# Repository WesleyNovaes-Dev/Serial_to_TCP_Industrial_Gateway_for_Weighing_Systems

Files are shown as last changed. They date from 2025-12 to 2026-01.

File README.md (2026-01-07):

# Serial-to-TCP Industrial Gateway for Weighing Systems
# 🚀 Gateway IoT Industrial – Integração de Balanças RS-232 com Redes TCP/IP  
### **Projeto Empresarial – Indústria 4.0 (NCH Brasil)**  
**Desenvolvido por:** *Wesley Davi Zanon Novaes*  






---

## 🌐 Visão Geral

Este repositório apresenta um **Gateway IoT Industrial** projetado para **modernizar balanças legadas** (RS-232 e USB) e conectá-las diretamente a redes corporativas para uso em sistemas ERP, MES, supervisórios e aplicações de automação industrial.

Diferente de um TCC acadêmico, este projeto é **uma evolução real** implantada e utilizada na **NCH Brasil**, rodando diariamente em ambiente de produção — com integração já validada com o ERP atual da empresa.

O objetivo central é simples e poderoso:

### **Transformar qualquer balança serial em um dispositivo inteligente totalmente integrado à Indústria 4.0.**

Sem alterar o hardware da balança.  
Sem custos abusivos de modernização.  
Sem soluções proprietárias fechadas.

---

## 🎯 Principais Benefícios

✔ **Elimina apontamentos manuais** de pesagem  
✔ **Reduz erros operacionais**  
✔ **Transmite dados em tempo real** via TCP/IP  
✔ **Suporte a Wi-Fi corporativo, incluindo WPA2-Enterprise (802.1X)**  
✔ **Interface Web moderna** para configuração completa do dispositivo  
✔ **Compatível com ERPs, bancos de dados, supervisórios e APIs**  
✔ **Plug-and-Play** (conecta → configura → integra)

---

## 🧩 Arquitetura Geral

A solução é composta por dois pilares principais:

### **1) Gateway IoT (ESP32)**
Responsável por:
- Receber dados via **RS-232 (UART + MAX3232)** ou USB
- Limpar, validar e tratar frames recebidos
- Detectar mudanças de peso (filtro inteligente)
- Transmitir dados via:
  - **TCP (porta configurável)**
  - **Servidor de Log**
- Servir uma **interface web avançada responsiva**
- Oferecer:
  - Configuração Wi-Fi
  - Configuração Ethernet (quando disponível)
  - IP estático/DHCP
  - Hostname
  - Baud Rate
  - Formato JSON / Texto puro
  - Múltiplos clientes simultâneos

### **2) Backend Integrado (Node.js)**
- Recebe e processa dados enviados pelo gateway
- Permite integração com:
  - ERPs
  - Sistemas legados
  - Bancos de dados
  - Dashboards e BI
- Registro de eventos e logs

---

## 🛠️ Hardware Utilizado

| Componente | Função |
|---|---|
| **ESP32 DevKitC V4** | Core de processamento e Wi-Fi |
| **MAX3232** | Conversão RS-232 → TTL |
| **DB9** | Interface com balanças industriais |
| **Fonte 5V** | Alimentação |
| **Protótipo final** | Pronto para migração a PCB industrial |

---

## 🔌 Conexões (Pinout Completo – ESP32 + MAX3232 + W5500)

| **ESP32** | **Dispositivo** | **Pino no Dispositivo** | **Função** |
|---|---|---|---|
| **GPIO 16 (RX2)** | MAX3232 | TX | Recepção da Balança (RS-232 → TTL) |
| **GPIO 17 (TX2)** | MAX3232 | RX | Envio para Balança (TTL → RS-232) |
| **GND** | MAX3232 | GND | Referência elétrica |
| **3.3V** | MAX3232 | VCC | Alimentação do conversor |
| **GPIO 18 (SCK)** | W5500 | SCLK | Clock SPI |
| **GPIO 19 (MISO)**  | W5500 | MISO | Dados do W5500 → ESP32 |
| **GPIO 23 (MOSI)**  | W5500 | MOSI | Dados do ESP32 → W5500 |
| **GPIO 5 (CS)** | W5500 | CS | Chip Select do módulo Ethernet |
| **GPIO 4 (RST)** | W5500 | RST | Reset do módulo Ethernet |
| **GND** | W5500 | GND | Referência elétrica |
| **3.3V ou 5V*** | W5500 | VCC | Alimentação (depende do módulo)** |
| **GPIO 2** | LED Indicador | LED | LED de status do sistema |

> **\*** A maioria dos módulos W5500 funciona com alimentação 3.3V lógica, porém muitos incluem regulador interno e aceitam 5V — verificar o modelo utilizado.

---

## 🧠 Funcionamento do Firmware

1. **Inicialização**  
   - Carrega credenciais
   - Tenta reconectar à última rede
   - Caso falhe → inicia **Modo AP de Configuração**

2. **Leitura da Balança (RS-232)**  
   - Captura bytes brutos
   - Limpa caracteres inválidos
   - Normaliza a string de peso
   - Filtra repetições para reduzir tráfego

3. **Transmissão dos Dados**  
   - Via Socket TCP (porta configurável)
   - Suporte a múltiplos clientes
   - Mecanismos:
     - Retry
     - Reconexão automática
     - Heartbeat de latência

4. **Webserver Interno**  
   - Configuração completa da rede
   - Exibição de status em tempo real
   - Dashboard de balance connection
   - Opções avançadas:
     - IP estático
     - WINS
     - DNS configurável
     - SoftAP customizável

---

## 📡 Integração com ERP (CONFIRMADA)

Este projeto já está homologado com o **ERP utilizado pela NCH Brasil**.

Isso inclui:
- Recebimento automático das pesagens
- Inserção de dados em rotinas internas
- Substituição de processos manuais
- Automação completa do fluxo de entrada de dados

---

## 📸 Screenshots (Inserir após subir as imagens)

> **Coloque as imagens no repositório e substitua pelos links:**

---

## 🌐 Demonstração Online

Acesse a página oficial do projeto:  
👉 **[https://digitalintegration.site/](https://serial-to-tcp-industrial-gateway-we-three.vercel.app/)** 

---

## 📦 Como Instalar

### **1) Firmware ESP32**
- Abra o projeto na Arduino IDE / PlatformIO
- Compile e carregue
- Ligue o dispositivo

### **2) Configuração Inicial**
- Conecte ao Wi-Fi exposto pelo dispositivo (SoftAP)
- Acesse `192.168.4.1`
- Configure:
  - SSID
  - Senha
  - DHCP/IP Estático
  - Enterprise (se necessário)
- Salve e reinicie

### **3) Conexão com ERP / Servidor**
- Configure seu sistema para conectar ao socket TCP
- Utilize a porta definida no painel do dispositivo
- Pronto — a balança está integrada!

---

## 📊 Performance e Resultados

| Métrica | Resultado |
|---|---|
| Latência média | **< 50ms** |
| Perda de pacotes | **0%** |
| Uptime testado | **> 3 horas contínuas** |
| Economia de tráfego (filtro inteligente) | **~90%** |

---

## 💡 Casos de Uso

- Pesagem industrial em tempo real  
- Controle de estoque e logística  
- Linhas de produção  
- Inspeção e controle de qualidade  
- Integração com ERPs corporativos  
- Automação de processos

---

## 🏭 Uso na NCH Brasil

O sistema está em **operação real** em ambiente industrial:  
- Implantado e rodando diariamente  
- Integrado com ERP oficial  
- Acompanhado por operadores e gestores  
- Atualizado continuamente como produto interno  
- Base para expansão a múltiplas unidades

---

👉 **Link do Site Explicativo:**  
[Serial_to_TCP_Industrial_Gateway_for_Weighing_Systems]()

👉 **Repositório do Site Explicativo:**  
[Serial_to_TCP_Industrial_Gateway_for_Weighing_Systems](https://github.com/WesleyNovaes-Dev/Serial_to_TCP_Industrial_Gateway_Web)

## 🤝 Contribuições

Sugestões, melhorias e pull requests são bem-vindos!

---

## 👨‍💻 Autor

**Wesley Davi Zanon Novaes**  
Engenharia de Computação – Desenvolvimento Embarcado  
Sorocaba – SP, Brasil  
Formado: Dez/2025.

📧 E-mail: **wesleyzanon.dev@gmail.com**  
📱 WhatsApp: **(11) 96583-5656**  
🌐 LinkedIn: *[https://www.linkedin.com/in/wesley-novaes-641577193/]*  

---

## ⭐ Se este projeto te ajudou...

Deixe uma **estrela ⭐ no repositório**. Isso ajuda muito!

---

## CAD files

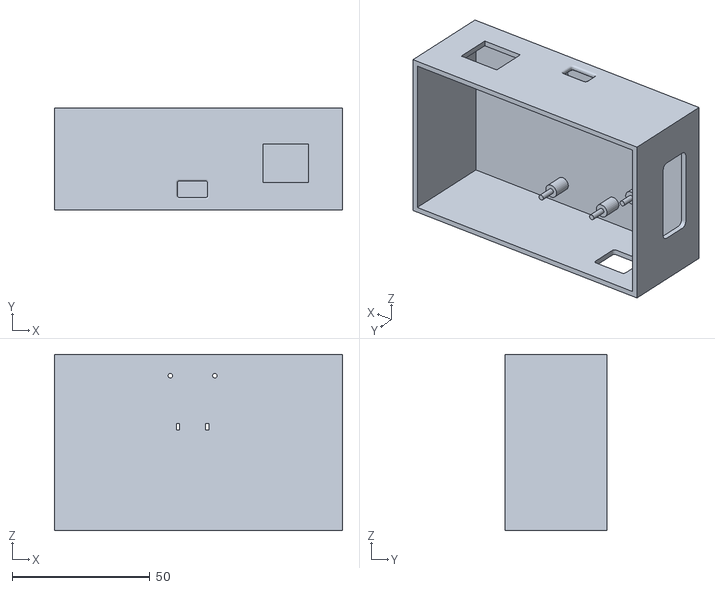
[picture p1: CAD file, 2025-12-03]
Case_3D/Corpo.stl
104.5 x 37.0 x 64.0

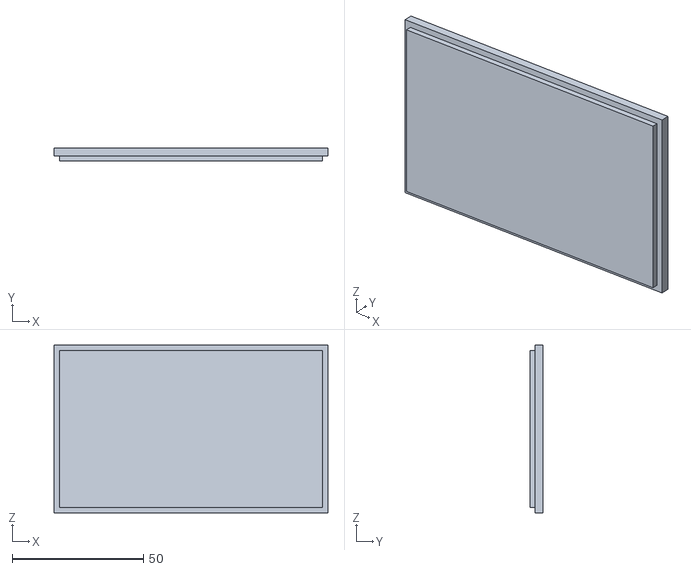
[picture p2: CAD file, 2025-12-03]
Case_3D/Tampa.stl
104.5 x 5.00 x 64.0

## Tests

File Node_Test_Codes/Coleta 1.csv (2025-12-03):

Data | Hora | DadoBruto | IP_Conexao
02/10/2025 | 18:27:20 | I00.010 | 10.128.32.178
02/10/2025 | 18:27:20 | I00.010 I00.010 I00.010 I00.010 I00.010 I00.010 I00.010 I00.010 I00.010 I00.010 I00.010 I00.010 I00.010 I00.010 I00.010 I00.010 I00.010 I00.010 I00.010 | 10.128.32.178
02/10/2025 | 18:27:21 | I00.030 I00.030 I00.030 I00.030 I00.030 I00.030 I00.030 I00.030 I00.030 I00.030 I00.030 I00.030 I00.030 I00.030 I00.030 I00.030 I00.030 I00.030 | 10.128.32.178
02/10/2025 | 18:27:21 | I00.030 I00.030 | 10.128.32.178
02/10/2025 | 18:27:21 | I00.050 I00.050 I00.050 I00.050 I00.050 I00.050 I00.050 I00.050 I00.050 I00.050 I00.050 I00.050 I00.050 I00.050 I00.050 I00.050 I00.050 I00.050 I00.050 I00.050 | 10.128.32.178
02/10/2025 | 18:27:21 | I00.065 I00.065 I00.065 I00.065 I00.065 I00.065 I00.065 I00.065 I00.065 I00.065 I00.065 I00.065 I00.065 I00.065 I00.065 I00.065 I00.065 I00.065 I00.065 I00.065 | 10.128.32.178
02/10/2025 | 18:27:21 | I00.070 I00.070 I00.070 I00.070 I00.070 I00.070 I00.070 I00.070 I00.070 I00.070 I00.070 I00.070 I00.070 I00.070 I00.070 I00.070 I00.070 I00.070 I00.070 I00.070 | 10.128.32.178
02/10/2025 | 18:27:22 | E00.070 | 10.128.32.178
02/10/2025 | 18:27:22 | E00.070 E00.070 E00.070 E00.070 E00.070 E00.070 E00.070 E00.070 E00.070 E00.070 E00.070 E00.070 E00.070 E00.070 E00.070 E00.070 E00.070 E00.070 E00.070 | 10.128.32.178
02/10/2025 | 18:27:23 | I00.075 | 10.128.32.178
02/10/2025 | 18:27:23 | I00.075 I00.075 I00.075 I00.075 I00.075 I00.075 I00.075 I00.075 I00.075 I00.075 I00.075 I00.075 I00.075 I00.075 I00.075 I00.075 I00.075 I00.075 I00.075 | 10.128.32.178
02/10/2025 | 18:27:23 | I00.090 | 10.128.32.178
02/10/2025 | 18:27:23 | I00.090 I00.090 I00.090 I00.090 I00.090 I00.090 I00.090 I00.090 I00.090 I00.090 I00.090 I00.090 I00.090 I00.090 I00.090 I00.090 I00.090 I00.090 I00.090 | 10.128.32.178
02/10/2025 | 18:27:23 | I00.110 | 10.128.32.178
02/10/2025 | 18:27:23 | I00.110 I00.110 I00.110 I00.110 I00.110 I00.110 I00.110 I00.110 I00.110 I00.110 I00.110 I00.110 I00.110 I00.110 I00.110 I00.110 I00.110 I00.110 I00.110 | 10.128.32.178
02/10/2025 | 18:27:23 | I00.130 I00.130 I00.130 I00.130 I00.130 I00.130 I00.130 I00.130 I00.130 I00.130 I00.130 I00.130 I00.130 I00.130 I00.130 I00.130 I00.130 I00.130 I00.130 I00.130 | 10.128.32.178
02/10/2025 | 18:27:23 | I00.125 | 10.128.32.178
02/10/2025 | 18:27:23 | I00.125 I00.125 I00.125 I00.125 I00.125 I00.125 I00.125 I00.125 I00.125 I00.125 I00.125 I00.125 I00.125 I00.125 I00.125 I00.125 I00.125 I00.125 I00.125 | 10.128.32.178
02/10/2025 | 18:27:24 | I00.130 | 10.128.32.178
02/10/2025 | 18:27:24 | I00.130 I00.130 I00.130 I00.130 I00.130 I00.130 I00.130 I00.130 I00.130 I00.130 I00.130 I00.130 I00.130 I00.130 I00.130 I00.130 I00.130 I00.130 I00.130 | 10.128.32.178
02/10/2025 | 18:27:24 | I00.140 | 10.128.32.178
02/10/2025 | 18:27:24 | I00.140 I00.140 I00.140 I00.140 I00.140 I00.140 I00.140 I00.140 I00.140 I00.140 I00.140 I00.140 I00.140 I00.140 I00.140 I00.140 I00.140 I00.140 I00.140 I00.160 I00.160 I00.160 I00.160 I00.160 I00.160 I00.160 | 10.128.32.178
02/10/2025 | 18:27:24 | I00.160 I00.160 I00.160 I00.160 I00.160 I00.160 I00.160 I00.160 I00.160 I00.160 I00.160 I00.160 I00.160 | 10.128.32.178
02/10/2025 | 18:27:24 | I00.175 I00.175 I00.175 I00.175 I00.175 I00.175 I00.175 I00.175 I00.175 I00.175 I00.175 I00.175 I00.175 I00.175 I00.175 I00.175 I00.175 I00.175 I00.175 | 10.128.32.178
02/10/2025 | 18:27:24 | I00.175 | 10.128.32.178
02/10/2025 | 18:27:24 | I00.180 I00.180 | 10.128.32.178
02/10/2025 | 18:27:24 | I00.180 I00.180 I00.180 I00.180 I00.180 I00.180 I00.180 I00.180 I00.180 I00.180 I00.180 I00.180 I00.180 I00.180 I00.180 I00.180 I00.180 I00.180 | 10.128.32.178
02/10/2025 | 18:27:25 | E00.180 | 10.128.32.178
02/10/2025 | 18:27:25 | E00.180 E00.180 E00.180 E00.180 E00.180 E00.180 E00.180 E00.180 E00.180 E00.180 E00.180 E00.180 E00.180 E00.180 E00.180 E00.180 E00.180 E00.180 E00.180 | 10.128.32.178
02/10/2025 | 18:27:29 | I00.175 | 10.128.32.178
02/10/2025 | 18:27:29 | I00.175 I00.175 I00.175 I00.175 I00.175 I00.175 I00.175 I00.175 I00.175 I00.175 I00.175 I00.175 I00.175 I00.175 I00.175 I00.175 I00.175 I00.175 I00.175 | 10.128.32.178
02/10/2025 | 18:27:29 | I00.150 | 10.128.32.178
02/10/2025 | 18:27:29 | I00.150 I00.150 I00.150 I00.150 I00.150 I00.150 I00.150 I00.150 I00.150 I00.150 I00.150 I00.150 I00.150 I00.150 I00.150 I00.150 I00.150 I00.150 I00.150 | 10.128.32.178
02/10/2025 | 18:27:30 | I00.110 | 10.128.32.178
02/10/2025 | 18:27:30 | I00.110 I00.110 I00.110 I00.110 I00.110 I00.110 I00.110 I00.110 I00.110 I00.110 I00.110 I00.110 I00.110 I00.110 I00.110 I00.110 I00.110 I00.110 I00.110 | 10.128.32.178
02/10/2025 | 18:27:30 | I00.075 I00.075 I00.075 I00.075 I00.075 I00.075 I00.075 I00.075 I00.075 I00.075 I00.075 I00.075 I00.075 I00.075 I00.075 I00.075 I00.075 I00.075 I00.075 I00.075 | 10.128.32.178
02/10/2025 | 18:27:30 | I00.055 I00.055 I00.055 I00.055 I00.055 I00.055 I00.055 I00.055 | 10.128.32.178
02/10/2025 | 18:27:30 | I00.055 I00.055 I00.055 I00.055 I00.055 I00.055 I00.055 I00.055 I00.055 I00.055 I00.055 I00.055 | 10.128.32.178
02/10/2025 | 18:27:30 | I00.050 | 10.128.32.178
02/10/2025 | 18:27:30 | I00.050 I00.050 I00.050 I00.050 I00.050 I00.050 I00.050 I00.050 I00.050 I00.050 I00.050 I00.050 I00.050 I00.050 I00.050 I00.050 I00.050 I00.050 I00.050 | 10.128.32.178
02/10/2025 | 18:27:31 | E00.050 | 10.128.32.178
02/10/2025 | 18:27:31 | E00.050 E00.050 E00.050 E00.050 E00.050 E00.050 E00.050 E00.050 E00.050 E00.050 E00.050 E00.050 E00.050 E00.050 E00.050 E00.050 E00.050 E00.050 E00.050 | 10.128.32.178
02/10/2025 | 18:27:31 | I00.045 | 10.128.32.178
02/10/2025 | 18:27:31 | I00.045 I00.045 I00.045 I00.045 I00.045 I00.045 I00.045 I00.045 I00.045 I00.045 I00.045 I00.045 I00.045 I00.045 I00.045 I00.045 I00.045 I00.045 I00.045 | 10.128.32.178
02/10/2025 | 18:27:32 | I00.035 I00.035 I00.035 I00.035 I00.035 I00.035 I00.035 I00.035 I00.035 I00.035 I00.035 I00.035 I00.035 I00.035 I00.035 I00.035 | 10.128.32.178
02/10/2025 | 18:27:32 | I00.035 I00.035 I00.035 I00.035 | 10.128.32.178
02/10/2025 | 18:27:32 | I00.020 | 10.128.32.178
02/10/2025 | 18:27:32 | I00.020 I00.020 I00.020 I00.020 I00.020 I00.020 I00.020 I00.020 I00.020 I00.020 I00.020 I00.020 I00.020 I00.020 I00.020 I00.020 I00.020 I00.020 I00.020 | 10.128.32.178
02/10/2025 | 18:27:32 | I00.005 | 10.128.32.178
02/10/2025 | 18:27:32 | I00.005 I00.005 I00.005 I00.005 I00.005 I00.005 I00.005 I00.005 I00.005 I00.005 I00.005 I00.005 I00.005 I00.005 I00.005 I00.005 I00.005 I00.005 I00.005 I00.000 I00.000 I00.000 I00.000 I00.000 I00.000 I00.000 I00.000 I00.000 I00.000 I00.000 I00.000 I00.000 I00.000 I00.000 I00.000 I00.000 I00.000 I00.000 I00.000 | 10.128.32.178
02/10/2025 | 18:27:33 | E00.000 | 10.128.32.178
02/10/2025 | 18:27:33 | E00.000 E00.000 E00.000 E00.000 E00.000 E00.000 E00.000 E00.000 E00.000 E00.000 E00.000 E00.000 E00.000 E00.000 E00.000 E00.000 E00.000 E00.000 E00.000 | 10.128.32.178

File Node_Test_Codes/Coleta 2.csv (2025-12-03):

Data | Hora | DadoBruto | IP_Conexao
02/10/2025 | 18:29:15 | I00.015 | 10.128.32.178
02/10/2025 | 18:29:15 | I00.015 I00.015 I00.015 I00.015 I00.015 I00.015 I00.015 I00.015 I00.015 I00.015 I00.015 I00.015 I00.015 I00.015 I00.015 I00.015 I00.015 I00.015 I00.015 | 10.128.32.178
02/10/2025 | 18:29:16 | I00.000 | 10.128.32.178
02/10/2025 | 18:29:16 | I00.000 I00.000 I00.000 I00.000 I00.000 I00.000 I00.000 I00.000 I00.000 I00.000 I00.000 I00.000 I00.000 I00.000 I00.000 I00.000 I00.000 I00.000 I00.000 | 10.128.32.178
02/10/2025 | 18:29:17 | E00.000 | 10.128.32.178
02/10/2025 | 18:29:17 | E00.000 E00.000 E00.000 E00.000 E00.000 E00.000 E00.000 E00.000 E00.000 E00.000 E00.000 E00.000 E00.000 E00.000 E00.000 E00.000 E00.000 E00.000 E00.000 | 10.128.32.178
02/10/2025 | 18:29:20 | I00.015 | 10.128.32.178
02/10/2025 | 18:29:20 | I00.015 I00.015 I00.015 I00.015 I00.015 I00.015 I00.015 I00.015 I00.015 I00.015 I00.015 I00.015 I00.015 I00.015 I00.015 I00.015 I00.015 I00.015 I00.015 | 10.128.32.178
02/10/2025 | 18:29:20 | I00.040 | 10.128.32.178
02/10/2025 | 18:29:20 | I00.040 I00.040 I00.040 I00.040 I00.040 I00.040 I00.040 I00.040 I00.040 I00.040 I00.040 I00.040 I00.040 I00.040 I00.040 I00.040 I00.040 I00.040 I00.040 | 10.128.32.178
02/10/2025 | 18:29:20 | I00.060 I00.060 I00.060 I00.060 | 10.128.32.178
02/10/2025 | 18:29:20 | I00.060 I00.060 I00.060 I00.060 I00.060 I00.060 I00.060 I00.060 I00.060 I00.060 I00.060 I00.060 I00.060 I00.060 I00.060 I00.060 | 10.128.32.178
02/10/2025 | 18:29:20 | I00.070 | 10.128.32.178
02/10/2025 | 18:29:20 | I00.070 I00.070 I00.070 I00.070 I00.070 I00.070 I00.070 I00.070 I00.070 I00.070 I00.070 I00.070 I00.070 I00.070 I00.070 I00.070 I00.070 I00.070 I00.070 | 10.128.32.178
02/10/2025 | 18:29:21 | E00.070 | 10.128.32.178
02/10/2025 | 18:29:21 | E00.070 E00.070 E00.070 E00.070 E00.070 E00.070 E00.070 E00.070 E00.070 E00.070 E00.070 E00.070 E00.070 E00.070 E00.070 E00.070 E00.070 E00.070 E00.070 | 10.128.32.178
02/10/2025 | 18:29:24 | I00.080 | 10.128.32.178
02/10/2025 | 18:29:24 | I00.080 I00.080 I00.080 I00.080 I00.080 I00.080 I00.080 I00.080 I00.080 I00.080 I00.080 I00.080 I00.080 I00.080 I00.080 I00.080 I00.080 I00.080 I00.080 | 10.128.32.178
02/10/2025 | 18:29:24 | I00.100 I00.100 I00.100 I00.100 I00.100 I00.100 I00.100 I00.100 I00.100 I00.100 I00.100 I00.100 | 10.128.32.178
02/10/2025 | 18:29:24 | I00.100 I00.100 I00.100 I00.100 I00.100 I00.100 I00.100 I00.100 | 10.128.32.178
02/10/2025 | 18:29:24 | I00.115 | 10.128.32.178
02/10/2025 | 18:29:24 | I00.115 I00.115 I00.115 I00.115 I00.115 I00.115 I00.115 I00.115 I00.115 I00.115 I00.115 I00.115 I00.115 I00.115 I00.115 I00.115 I00.115 I00.115 I00.115 | 10.128.32.178
02/10/2025 | 18:29:24 | I00.125 I00.125 I00.125 I00.125 I00.125 I00.125 | 10.128.32.178
02/10/2025 | 18:29:25 | I00.125 I00.125 I00.125 I00.125 I00.125 I00.125 I00.125 I00.125 I00.125 I00.125 I00.125 I00.125 I00.125 I00.125 | 10.128.32.178
02/10/2025 | 18:29:26 | E00.125 | 10.128.32.178
02/10/2025 | 18:29:26 | E00.125 E00.125 E00.125 E00.125 E00.125 E00.125 E00.125 E00.125 E00.125 E00.125 E00.125 E00.125 E00.125 E00.125 E00.125 E00.125 E00.125 E00.125 E00.125 | 10.128.32.178
02/10/2025 | 18:29:27 | I00.120 | 10.128.32.178
02/10/2025 | 18:29:27 | I00.120 I00.120 I00.120 I00.120 I00.120 I00.120 I00.120 I00.120 I00.120 I00.120 I00.120 I00.120 I00.120 I00.120 I00.120 I00.120 I00.120 I00.120 I00.120 | 10.128.32.178
02/10/2025 | 18:29:27 | I00.095 I00.095 I00.095 I00.095 I00.095 I00.095 I00.095 I00.095 I00.095 I00.095 I00.095 I00.095 I00.095 I00.095 I00.095 I00.095 I00.095 I00.095 I00.095 I00.095 | 10.128.32.178
02/10/2025 | 18:29:27 | I00.055 | 10.128.32.178
02/10/2025 | 18:29:27 | I00.055 I00.055 I00.055 I00.055 I00.055 I00.055 I00.055 I00.055 I00.055 I00.055 I00.055 I00.055 I00.055 I00.055 I00.055 I00.055 I00.055 I00.055 I00.055 | 10.128.32.178
02/10/2025 | 18:29:28 | I00.020 I00.020 I00.020 I00.020 I00.020 I00.020 I00.020 I00.020 I00.020 I00.020 I00.020 I00.020 I00.020 I00.020 I00.020 I00.020 I00.020 I00.020 I00.020 I00.020 | 10.128.32.178
02/10/2025 | 18:29:28 | I00.005 I00.005 I00.005 I00.005 I00.005 I00.005 | 10.128.32.178
02/10/2025 | 18:29:28 | I00.005 I00.005 I00.005 I00.005 I00.005 I00.005 I00.005 I00.005 I00.005 I00.005 I00.005 I00.005 I00.005 I00.005 | 10.128.32.178
02/10/2025 | 18:29:28 | I00.000 I00.000 I00.000 I00.000 I00.000 I00.000 I00.000 I00.000 I00.000 I00.000 I00.000 I00.000 I00.000 I00.000 I00.000 I00.000 I00.000 I00.000 I00.000 I00.000 | 10.128.32.178
02/10/2025 | 18:29:29 | E00.000 | 10.128.32.178
02/10/2025 | 18:29:29 | E00.000 E00.000 E00.000 E00.000 E00.000 E00.000 E00.000 E00.000 E00.000 E00.000 E00.000 E00.000 E00.000 E00.000 E00.000 E00.000 E00.000 E00.000 E00.000 | 10.128.32.178

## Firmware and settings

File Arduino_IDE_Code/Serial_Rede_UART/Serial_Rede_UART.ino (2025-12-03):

#include <WiFi.h>
#include <ESPmDNS.h>
#include <WiFiUdp.h>
#include <ArduinoOTA.h>
#include <Preferences.h>
#include "esp_eap_client.h"
#include <IPAddress.h>
#include <vector>
#include <stdarg.h>
#include <memory>

#include <SPI.h>
#include <Ethernet.h>

// ========== 1. DEFINIÇÕES E PINAGEM ==========
const int ledPin = 2;

// SERIAL RS232 (Balança)
#define RS232_TX 17
#define RS232_RX 16

// W5500 SPI pins
#define W5500_SCLK  18
#define W5500_MISO  19
#define W5500_MOSI  23
#define W5500_CS    5
#define W5500_RST   4

// MAC Address para Ethernet
byte mac[] = { 0xDE, 0xAD, 0xBE, 0xEF, 0xFE, 0x05 };

// Configurações de Tempo
const long SOFTAP_GRACE_PERIOD_MS = 60000;
const long NETWORK_CHECK_INTERVAL = 15000; // 15 segundos para reconexão
const unsigned long WEB_POST_READ_TIMEOUT = 800;
const unsigned long RS232_POLL_INTERVAL = 1;
const unsigned long STATUS_LOG_INTERVAL = 60000; // 1 minuto
const unsigned long BALANCE_CHECK_INTERVAL = 5000; // Verificar balança a cada 5s

// ========== 2. ESTRUTURAS E ENUMS ==========
struct AuthClient {
    std::shared_ptr<Client> client;
    String ip;
    unsigned long lastSentMs = 0;
};

struct WinsConfig {
    String wins1;
    String wins2;
};

enum NetworkMode { 
    NET_NONE, 
    NET_SOFTAP, 
    NET_WIFI, 
    NET_ETHERNET 
};

enum LedStatus {
    LED_OFF,
    LED_ON,
    LED_BLINK_SLOW,    // Modo AP/Configuração
    LED_BLINK_FAST,    // Conectando
    LED_BLINK_DOUBLE   // Erro
};

// ========== 3. OBJETOS GLOBAIS ==========
NetworkMode currentMode = NET_NONE;
LedStatus currentLedStatus = LED_OFF;

HardwareSerial SerialRS232(2);
Preferences prefs;

// Servidores
WiFiServer wifiWeb(80);
WiFiServer wifiData(9000);
WiFiServer wifiLog(5000);

EthernetServer ethWeb(80);
EthernetServer ethData(9000);
EthernetServer ethLog(5000);

// Clientes
std::vector<AuthClient> dataClients;
std::vector<AuthClient> logClients;

// ========== 4. CONFIGURAÇÕES PERSISTENTES ==========
String adminPassword = "";
String deviceHostname = "esp32-balanca-Generic";
long rs232Baud = 9600;
uint16_t dataPort = 9000;
uint16_t logPort = 5000;
String lastSoftApPass = "12345678";
String softApSSID = "ESP32_Balanca_Config_Generic";

// Configurações de Rede
String lastSSID = "", lastPass = "", lastUser = "";
bool lastEnterprise = false;
bool lastUseStaticIP = false;
String lastStaticIP = "", lastSubnet = "", lastGateway = "", lastDns1 = "", lastDns2 = "";
WinsConfig winsConfig = {"", ""};

// Configurações do Sistema
bool lastUseLCD = false;
bool enableLineChangeDetector = false;
int dataSendFormat = 1;
bool sendAlways = true;

// ========== 5. VARIÁVEIS DE ESTADO ==========
bool connectionJustSucceeded = false;
unsigned long connectionSuccessTime = 0;
unsigned long ledPreviousMillis = 0;
const long ledInterval = 500;
bool isRs232Active = false;
unsigned long lastNetworkCheck = 0;
unsigned long softApStartTime = 0;
unsigned long lastStatusLogTime = 0;
unsigned long lastBalanceCheck = 0;
unsigned long lastReconnectAttempt = 0;

// Buffer de Dados
String currentWeightBuffer = "";
String lastSentWeight = "";
String serialUsbBuffer = "";

// Controle LED
unsigned long lastLedChange = 0;
int ledBlinkState = LOW;

// Estado do Sistema
bool balanceConnected = false;
bool networkConnected = false;
String lastWebAlert = "";

// ========== 6. PROTÓTIPOS ==========
void app_log(const char *format, ...);
void saveCredentials();
void loadCredentials();
void clearCredentials();
void startSoftAP();
void stopSoftAP();
void stopNetwork();
bool startEthernet();
bool startWiFi();
void manageNetwork();
void handleDataClient();
void handleLogClients();
void broadcastWeightAndClientStatusToLog(String cleanWeight);
String urlDecode(String str);
String getParam(String req, String key);
template <typename T> void handleWebClientGeneric(T client);

// Novas funções
void setLedStatus(LedStatus status);
void updateLed();
void performFactoryReset();
void processSerialUSBCommands();
void resetW5500();
IPAddress strToIP(String s);
void checkSerialState();
String cleanWeightLine(const String &line);
void broadcastDataToClients(const String &payload);
void processRS232();
void startServicesHibrido();
void checkBalanceConnection();
void attemptReconnect();
String getNetworkStatusJSON();
String scanWiFiNetworks();
String generateWebInterface();

// ========== 7. SISTEMA DE LOG COMPLETO ==========
void app_log(const char *format, ...) {
    char buf[512];
    va_list args;
    va_start(args, format);
    vsnprintf(buf, sizeof(buf), format, args);
    va_end(args);
    
    // Log na Serial
    Serial.print(buf);
    
    // Log para clientes de LOG apenas se houver conexão de rede
    if (networkConnected && dataClients.empty()) {
        for (int i = (int)logClients.size() - 1; i >= 0; i--) {
            if (logClients[i].client && logClients[i].client->connected()) {
                logClients[i].client->write((uint8_t*)buf, strlen(buf));
            } else {
                if (logClients[i].client) logClients[i].client->stop();
                logClients.erase(logClients.begin() + i);
            }
        }
    }
}

// ========== 8. SISTEMA LED ==========
void setLedStatus(LedStatus status) {
    currentLedStatus = status;
    lastLedChange = millis();
    ledBlinkState = LOW;
    
    switch(status) {
        case LED_OFF:
            digitalWrite(ledPin, LOW);
            break;
        case LED_ON:
            digitalWrite(ledPin, HIGH);
            break;
        case LED_BLINK_SLOW:  // 1Hz - Modo AP
        case LED_BLINK_FAST:  // 2Hz - Conectando
        case LED_BLINK_DOUBLE: // Pisca duplo - Erro
            digitalWrite(ledPin, LOW);
            break;
    }
}

void updateLed() {
    unsigned long currentMillis = millis();
    long interval = 0;
    
    switch(currentLedStatus) {
        case LED_BLINK_SLOW:
            interval = 1000; break;
        case LED_BLINK_FAST:
            interval = 500; break;
        case LED_BLINK_DOUBLE:
            interval = 300; break;
        default:
            return;
    }
    
    if (currentMillis - lastLedChange >= interval) {
        lastLedChange = currentMillis;
        
        if (currentLedStatus == LED_BLINK_DOUBLE) {
            // Pisca duplo especial
            static int doubleBlinkPhase = 0;
            switch(doubleBlinkPhase) {
                case 0: digitalWrite(ledPin, HIGH); break;
                case 1: digitalWrite(ledPin, LOW); break;
                case 2: digitalWrite(ledPin, HIGH); break;
                case 3: digitalWrite(ledPin, LOW); break;
            }
            doubleBlinkPhase = (doubleBlinkPhase + 1) % 4;
        } else {
            // Pisca normal
            ledBlinkState = !ledBlinkState;
            digitalWrite(ledPin, ledBlinkState);
        }
    }
}

// ========== 9. BROADCAST E LOGS ==========
void broadcastWeightAndClientStatusToLog(String cleanWeight) {
    if (logClients.empty() || !networkConnected) return;
    
    String dataClientList = "";
    for (const auto& client : dataClients) {
        if (!dataClientList.isEmpty()) dataClientList += ", ";
        dataClientList += client.ip;
    }
    if (dataClientList.isEmpty()) dataClientList = "Nenhum";

    String logClientList = "";
    for (const auto& client : logClients) {
        if (!logClientList.isEmpty()) logClientList += ", ";
        logClientList += client.ip;
    }

    String balanceStatus = balanceConnected ? "Conectada" : "DESLIGADA";
    
    String logPayload = "[PESO]|" + cleanWeight +
                       "|Balança: " + balanceStatus +
                       "|Clientes Dados (" + String(dataClients.size()) + "): " + dataClientList +
                       "|Clientes Log (" + String(logClients.size()) + "): " + logClientList +
                       "|Rede: " + String(currentMode == NET_ETHERNET ? "CABO" : 
                                       currentMode == NET_WIFI ? "WiFi" : "AP") +
                       "\n";

    for (int i = (int)logClients.size() - 1; i >= 0; i--) {
        if (logClients[i].client && logClients[i].client->connected()) {
            logClients[i].client->write((const uint8_t*)logPayload.c_str(), logPayload.length());
        } else {
            if (logClients[i].client) logClients[i].client->stop();
            logClients.erase(logClients.begin() + i);
        }
    }
}

// ========== 10. GESTÃO DE REDE REFATORADA ==========
IPAddress strToIP(String s) { 
    IPAddress ip; 
    if (s.length() > 0) {
        ip.fromString(s); 
    }
    return ip; 
}

void resetW5500() {
    pinMode(W5500_RST, OUTPUT);
    digitalWrite(W5500_RST, LOW); 
    delay(200);
    digitalWrite(W5500_RST, HIGH); 
    delay(200);
}

void stopNetwork() {
    app_log("[REDE] Parando serviços de rede...\n");
    
    if (currentMode == NET_WIFI || currentMode == NET_SOFTAP) {
        WiFi.disconnect(true);
        WiFi.mode(WIFI_OFF);
    }
    
    currentMode = NET_NONE;
    networkConnected = false;
    
    // Limpa clientes
    for (auto &c : dataClients) if (c.client) c.client->stop();
    for (auto &c : logClients) if (c.client) c.client->stop();
    dataClients.clear(); 
    logClients.clear();
    
    setLedStatus(LED_BLINK_SLOW);
}

void startServicesHibrido() {
    app_log("[SERVICOS] Iniciando serviços...\n");
    
    if (currentMode == NET_ETHERNET) {
        ethWeb.begin();
        ethData.begin();
        ethLog.begin();
        app_log("[SERVICOS] Servidores Ethernet iniciados\n");
    } else {
        wifiWeb.begin();
        wifiData.begin(dataPort);
        wifiLog.begin(logPort);
        app_log("[SERVICOS] Servidores WiFi iniciados\n");
    }

    // mDNS
    MDNS.end();
    if (!MDNS.begin(deviceHostname.c_str())) {
        app_log("[SERVICOS] Erro ao iniciar mDNS!\n");
    } else {
        app_log("[SERVICOS] mDNS: http://%s.local\n", deviceHostname.c_str());
        MDNS.addService("http", "tcp", 80);
        MDNS.addService("balanca-data", "tcp", dataPort);
    }

    // OTA apenas para WiFi
    if (currentMode == NET_WIFI || currentMode == NET_SOFTAP) {
        ArduinoOTA.setHostname(deviceHostname.c_str());
        if (adminPassword.length() > 0) {
            ArduinoOTA.setPassword(adminPassword.c_str());
        }
        ArduinoOTA.begin();
        app_log("[SERVICOS] OTA pronto\n");
    }
    
    app_log("[SERVICOS] Serviços online - Web:80, Dados:%d, Log:%d\n", dataPort, logPort);
    connectionJustSucceeded = true;
    connectionSuccessTime = millis();
    networkConnected = true;
}

bool startEthernet() {
    stopNetwork();
    app_log("[ETHERNET] Iniciando conexão por cabo...\n");
    setLedStatus(LED_BLINK_FAST);
    
    resetW5500();
    Ethernet.init(W5500_CS);

    int dhcpStatus = 0;
    if (lastUseStaticIP && lastStaticIP.length() > 0) {
        app_log("[ETHERNET] IP Estático: %s\n", lastStaticIP.c_str());
        IPAddress ip = strToIP(lastStaticIP);
        IPAddress gateway = strToIP(lastGateway);
        IPAddress subnet = strToIP(lastSubnet);
        IPAddress dns1 = strToIP(lastDns1);
        IPAddress dns2 = strToIP(lastDns2);
        
        if (dns1 != INADDR_NONE) {
            Ethernet.begin(mac, ip, dns1, gateway, subnet);
        } else {
            Ethernet.begin(mac, ip, gateway, subnet);
        }
        dhcpStatus = 1;
    } else {
        app_log("[ETHERNET] DHCP: Solicitando...\n");
        dhcpStatus = Ethernet.begin(mac, 10000); // Timeout de 10s
    }

    if (dhcpStatus == 0) {
        app_log("[ETHERNET] Falha - Sem cabo/DHCP\n");
        setLedStatus(LED_BLINK_DOUBLE);
        return false;
    }

    app_log("[ETHERNET] Conectado! IP: %s\n", Ethernet.localIP().toString().c_str());
    currentMode = NET_ETHERNET;
    startServicesHibrido();
    setLedStatus(LED_ON);
    return true;
}

bool startWiFi() {
    stopNetwork();
    
    if (lastSSID == "") { 
        app_log("[WIFI] Nenhuma rede configurada\n"); 
        return false; 
    }

    app_log("[WIFI] Conectando: %s\n", lastSSID.c_str());
    setLedStatus(LED_BLINK_FAST);
    
    WiFi.mode(WIFI_STA);

    // Configuração IP estático para WiFi
    if (lastUseStaticIP && lastStaticIP.length() > 0) {
        app_log("[WIFI] IP Estático: %s\n", lastStaticIP.c_str());
        IPAddress ip = strToIP(lastStaticIP);
        IPAddress gateway = strToIP(lastGateway);
        IPAddress subnet = strToIP(lastSubnet);
        IPAddress dns1 = strToIP(lastDns1);
        IPAddress dns2 = strToIP(lastDns2);
        
        if (dns1 != INADDR_NONE || dns2 != INADDR_NONE) {
            if (dns1 != INADDR_NONE && dns2 != INADDR_NONE) {
                WiFi.config(ip, gateway, subnet, dns1, dns2);
            } else if (dns1 != INADDR_NONE) {
                WiFi.config(ip, gateway, subnet, dns1);
            }
        } else {
            WiFi.config(ip, gateway, subnet);
        }
    }

    // Configuração Enterprise 802.1x
    if (lastEnterprise) {
        app_log("[WIFI] Modo Enterprise 802.1x - Usuário: %s\n", lastUser.c_str());
        esp_eap_client_set_identity((uint8_t*)lastUser.c_str(), lastUser.length());
        esp_eap_client_set_username((uint8_t*)lastUser.c_str(), lastUser.length());
        esp_eap_client_set_password((uint8_t*)lastPass.c_str(), lastPass.length());
        esp_wifi_sta_enterprise_enable();
        WiFi.begin(lastSSID.c_str());
    } else {
        WiFi.begin(lastSSID.c_str(), lastPass.c_str());
    }

    int attempts = 0;
    while (WiFi.status() != WL_CONNECTED && attempts < 30) { // 15s timeout
        delay(500); 
        app_log("."); 
        attempts++;
        if (attempts % 4 == 0) yield();
    }
    app_log("\n");

    if (WiFi.status() == WL_CONNECTED) {
        app_log("[WIFI] Conectado! IP: %s\n", WiFi.localIP().toString().c_str());
        currentMode = NET_WIFI;
        startServicesHibrido();
        setLedStatus(LED_ON);
        return true;
    } else {
        app_log("[WIFI] Falha na conexão\n");
        setLedStatus(LED_BLINK_DOUBLE);
        return false;
    }
}

void startSoftAP() {
    stopNetwork();
    app_log("[SOFTAP] Iniciando modo configuração...\n");
    
    WiFi.mode(WIFI_AP_STA);
    WiFi.softAP(softApSSID.c_str(), lastSoftApPass.c_str());
    
    currentMode = NET_SOFTAP;
    startServicesHibrido();
    
    IPAddress IP = WiFi.softAPIP();
    app_log("[SOFTAP] Pronto! IP: %s - Senha: %s\n", IP.toString().c_str(), lastSoftApPass.c_str());
    
    softApStartTime = millis();
    setLedStatus(LED_BLINK_SLOW);
}

void stopSoftAP() {
    if (WiFi.getMode() == WIFI_AP_STA) {
        WiFi.softAPdisconnect(true);
        app_log("[SOFTAP] Desativado\n");
    }
}

void attemptReconnect() {
    if (millis() - lastReconnectAttempt < NETWORK_CHECK_INTERVAL) return;
    lastReconnectAttempt = millis();
    
    // Verifica se temos credenciais salvas
    if (lastSSID.length() > 0) {
        app_log("[RECONEXAO] Tentando reconectar à rede salva...\n");
        if (startWiFi()) {
            app_log("[RECONEXAO] Reconexão bem-sucedida!\n");
        } else {
            app_log("[RECONEXAO] Falha na reconexão\n");
        }
    }
}

void manageNetwork() {
    if (millis() - lastNetworkCheck < NETWORK_CHECK_INTERVAL) return;
    lastNetworkCheck = millis();

    // Verifica status do cabo Ethernet
    bool cableConnected = (Ethernet.linkStatus() == LinkON);
    bool wifiConnected = (WiFi.status() == WL_CONNECTED);

    // Lógica de failover inteligente
    if (cableConnected && currentMode != NET_ETHERNET) {
        app_log("[FAILOVER] Cabo detectado - Mudando para Ethernet\n");
        if (!startEthernet()) {
            if (currentMode == NET_NONE && !startWiFi()) {
                startSoftAP();
            }
        }
    } 
    else if (!cableConnected && currentMode == NET_ETHERNET) {
        app_log("[FAILOVER] Cabo desconectado - Tentando WiFi\n");
        if (!startWiFi()) {
            app_log("[FAILOVER] WiFi falhou - Iniciando SoftAP\n");
            startSoftAP();
        }
    }
    // Se desconectou do WiFi, tenta reconectar ou vai para Ethernet
    else if (currentMode == NET_WIFI && !wifiConnected) {
        app_log("[FAILOVER] WiFi desconectado - Tentando reconectar\n");
        attemptReconnect();
    }
    // Se está em modo AP mas há redes salvas, tenta reconectar periodicamente
    else if (currentMode == NET_SOFTAP && lastSSID.length() > 0) {
        attemptReconnect();
    }

    // Timeout do SoftAP se ninguém conectar
    if (currentMode == NET_SOFTAP && WiFi.softAPgetStationNum() == 0) {
        if (millis() - softApStartTime > (SOFTAP_GRACE_PERIOD_MS * 5)) {
            app_log("[SOFTAP] Timeout - Tentando reconexão...\n");
            if (lastSSID.length() > 0 && !startWiFi()) {
                if (cableConnected && !startEthernet()) {
                    app_log("[SOFTAP] Nenhuma conexão disponível - Mantendo AP\n");
                    softApStartTime = millis(); // Reseta o timer
                }
            }
        }
    }
}

// ========== 11. PERSISTÊNCIA ==========
void saveCredentials() {
    prefs.begin("wifiCreds", false);
    prefs.putString("ssid", lastSSID);
    prefs.putString("pass", lastPass);
    prefs.putString("user", lastUser);
    prefs.putBool("enterprise", lastEnterprise);
    prefs.putBool("useStatic", lastUseStaticIP);
    if (lastUseStaticIP) {
        prefs.putString("staticIP", lastStaticIP);
        prefs.putString("subnet", lastSubnet);
        prefs.putString("gateway", lastGateway);
        prefs.putString("dns1", lastDns1);
        prefs.putString("dns2", lastDns2);
        prefs.putString("wins1", winsConfig.wins1);
        prefs.putString("wins2", winsConfig.wins2);
    }
    prefs.end();

    prefs.begin("sysConfig", false);
    prefs.putString("admPass", adminPassword);
    prefs.putString("hostname", deviceHostname);
    prefs.putUShort("dPort", dataPort);
    prefs.putUShort("lPort", logPort);
    prefs.putLong("baud", rs232Baud);
    prefs.putInt("dsf", dataSendFormat);
    prefs.putString("softap", lastSoftApPass);
    prefs.putString("softapssid", softApSSID);
    prefs.putBool("useLCD", lastUseLCD);
    prefs.putBool("sendAlways", sendAlways);
    prefs.end();
    
    app_log("[CONFIG] Credenciais salvas\n");
}

void loadCredentials() {
    prefs.begin("wifiCreds", true);
    lastSSID = prefs.getString("ssid", "");
    lastPass = prefs.getString("pass", "");
    lastUser = prefs.getString("user", "");
    lastEnterprise = prefs.getBool("enterprise", false);
    lastUseStaticIP = prefs.getBool("useStatic", false);
    lastStaticIP = prefs.getString("staticIP", "");
    lastSubnet = prefs.getString("subnet", "");
    lastGateway = prefs.getString("gateway", "");
    lastDns1 = prefs.getString("dns1", "");
    lastDns2 = prefs.getString("dns2", "");
    winsConfig.wins1 = prefs.getString("wins1", "");
    winsConfig.wins2 = prefs.getString("wins2", "");
    prefs.end();

    prefs.begin("sysConfig", true);
    adminPassword = prefs.getString("admPass", "");
    deviceHostname = prefs.getString("hostname", "esp32-balanca-Generic");
    dataPort = prefs.getUShort("dPort", 9000);
    logPort = prefs.getUShort("lPort", 5000);
    rs232Baud = prefs.getLong("baud", 9600);
    dataSendFormat = prefs.getInt("dsf", 1);
    lastSoftApPass = prefs.getString("softap", "12345678");
    softApSSID = prefs.getString("softapssid", "ESP32_Balanca_Config_Generic");
    lastUseLCD = prefs.getBool("useLCD", true);
    sendAlways = prefs.getBool("sendAlways", true);
    prefs.end();

    enableLineChangeDetector = lastUseLCD;
    app_log("[CONFIG] Configurações carregadas\n");
}
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
void loop() {
    // Gestão de Rede
    manageNetwork();

    // Atualização LED
    updateLed();

    // OTA Updates (apenas WiFi)
    if (currentMode == NET_WIFI || currentMode == NET_SOFTAP || currentMode == NET_ETHERNET) {
        ArduinoOTA.handle();
    }

    // Desativa SoftAP após conexão estabelecida
    if (currentMode != NET_SOFTAP && connectionJustSucceeded && 
        (millis() - connectionSuccessTime > SOFTAP_GRACE_PERIOD_MS)) {
        stopSoftAP(); 
        connectionJustSucceeded = false;
    }

    // LOG DE STATUS A CADA 1 MINUTO (apenas se houver conexão de rede)
    if (networkConnected && millis() - lastStatusLogTime > STATUS_LOG_INTERVAL) {
        lastStatusLogTime = millis();
        String statusMsg = "\n[STATUS 1min] -----------------------------\n";
        statusMsg += "Conexao: " + String(currentMode == NET_ETHERNET ? "CABO (RJ45)" : (currentMode == NET_WIFI ? "WIFI" : "AP Mode")) + "\n";
        statusMsg += "IP: " + (currentMode == NET_ETHERNET ? Ethernet.localIP().toString() : WiFi.localIP().toString()) + "\n";
        statusMsg += "Hostname: " + deviceHostname + "\n";
        statusMsg += "Clientes LOG: " + String(logClients.size()) + " | Clientes DADOS: " + String(dataClients.size()) + "\n";
        statusMsg += "Balança: " + String(balanceConnected ? "Conectada" : "DESLIGADA") + " | Alerta: " + lastWebAlert + "\n";
        statusMsg += "Config: LCD=" + String(lastUseLCD?"ON":"OFF") + " | EnviarSempre=" + String(sendAlways?"ON":"OFF") + "\n";
        statusMsg += "Ultimo Peso: " + lastSentWeight + "\n";
        statusMsg += "---------------------------------------------\n";
        app_log(statusMsg.c_str());
    }

    // Verificação da Balança
    checkBalanceConnection();

    // Processamento Serial e RS232
    processSerialUSBCommands();
    processRS232();

    // Serviços Web
    if (currentMode == NET_ETHERNET) {
        EthernetClient cl = ethWeb.available();
        if (cl) handleWebClientGeneric(cl);
    } else if (currentMode == NET_WIFI || currentMode == NET_SOFTAP) {
        WiFiClient cl = wifiWeb.available();
        if (cl) handleWebClientGeneric(cl);
    }

    // Clientes de Dados e Log
    handleLogClients();
    handleDataClient();

    // Não bloquear o loop
    delay(1);
}
